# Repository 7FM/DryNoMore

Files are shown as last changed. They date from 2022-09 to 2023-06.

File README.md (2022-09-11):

# DryNoMore

TODO description, images, etc.

## Software

### Get the sources
- `git clone --recursive https://github.com/7FM/DryNoMore.git`
- Or `git clone https://github.com/7FM/DryNoMore.git` followed by `git submodule update --init --recursive`

### Dependencies
<details>
  <summary>For Debian:</summary>

```
apt install git git-lfs gcc make binutils cmake libssl-dev libboost-system-dev zlib1g-dev libyaml-cpp-dev 
```
Note that you will need `gcc-11` to compile the telegram bot, as it uses `std::bit_cast` (added in C++20).
Debian bullseye uses `gcc-10` by default and `g++-11` is currently only available in the testing channel.
Hence, you must add 
```
deb http://httpredir.debian.org/debian testing main contrib non-free
```
to `/etc/apt/sources.list`.
To avoid updating all packages to the testing channel create the file `/etc/apt/preferences.d/unstable-preferences` with the following content:
```
Package: *
Pin: release  a=testing
Pin-Priority: 100

Package: *
Pin: release a=unstable
Pin-Priority: 200
```
Then you can use `apt -t testing install gcc` to install `gcc-11`.
</details>

For NixOS see [`flake.nix`](./flake.nix).

### Compilation
- For the Arduino project simply use PlatformIO, i.e. through the [PlatformIO IDE](https://platformio.org/install/ide?install=vscode).
- For the Telegram Bot simply go into the folder `server/telegram_bot` and run `make`. On success a binary should be present at `server/telegram_bot/build/drynomore-telegram-bot`

### Configuration

<details>
  <summary>Configure the Arduino Project:</summary>

- all major settings are adjustable in the [`config.hpp`](./include/config.hpp)

TODO list options
</details>
<details>
  <summary>Configure the Telegram Bot:</summary>

- all major settings are adjustable though a YAML config file. As an example take a look at the [`example_config.yaml`](./server/telegram_bot/example_config.yaml).

TODO list options
</details>

## Hardware
### Known Flaws:
- v0.1:
    - Barrel Jack power input (J10) has swapped polarity.
- v0.2:
    - Main power consumption is caused by the W5500 Ethernet module

### Changelog:
#### v0.1 &rarr; v0.2:
- fix power input polarity
#### v0.2 &rarr; v0.3
- add mosfet to switch off the W5500 Ethernet module

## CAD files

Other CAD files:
hardware/case/DryNoMoreCase.FCStd
hardware/case/Top.stl
hardware/case/Base.stl

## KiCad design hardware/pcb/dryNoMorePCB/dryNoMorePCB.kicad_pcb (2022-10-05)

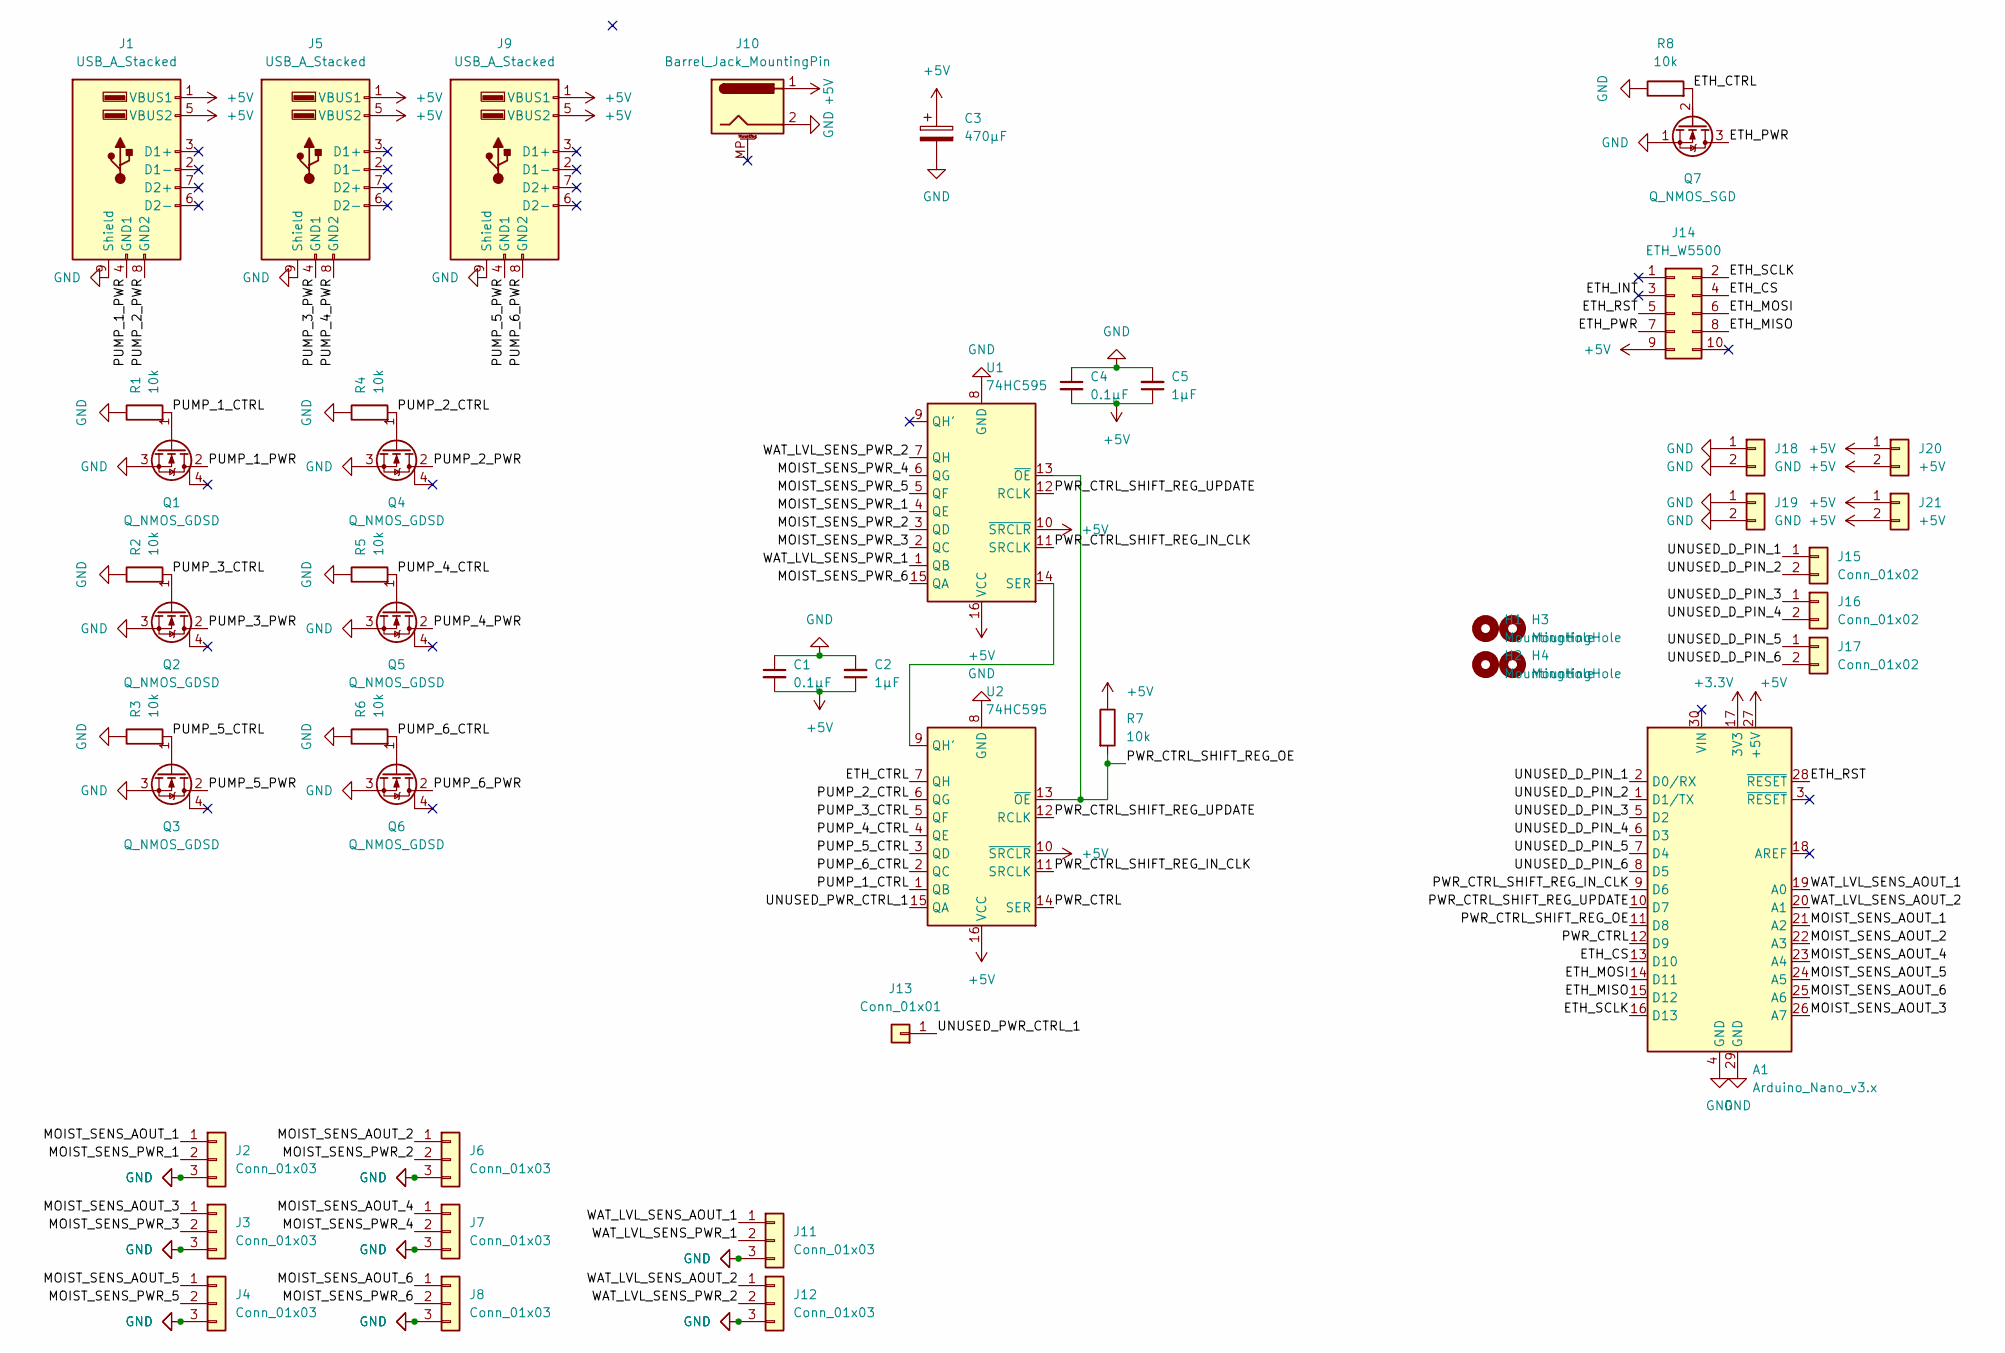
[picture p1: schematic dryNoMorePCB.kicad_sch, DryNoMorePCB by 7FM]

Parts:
A1: Arduino_Nano_v3.x; Arduino_Nano
C1, C4: 0.1µF; C_Disc_D3.8mm_W2.6mm_P2.50mm
C2, C5: 1µF; C_Rect_L4.0mm_W2.5mm_P2.50mm
C3: 470µF; CP_Radial_D8.0mm_P3.50mm
H1, H2, H3, H4: MountingHole; MountingHole_3.2mm_M3_DIN965
J1, J5, J9: USB_A_Stacked; USB_A_Wuerth_61400826021_Horizontal_Stacked
J2, J3, J4, J6, J7, J8, J11, J12: Conn_01x03; PinHeader_1x03_P2.54mm_Vertical
J10: Barrel_Jack_MountingPin; BarrelJack_Horizontal
J13: Conn_01x01; PinHeader_1x01_P2.54mm_Vertical
J14: ETH_W5500; PinSocket_2x05_P2.54mm_Vertical
J15, J16, J17: Conn_01x02; PinHeader_1x02_P2.54mm_Vertical
J18, J19: GND; PinHeader_1x02_P2.54mm_Vertical
J20, J21: +5V; PinHeader_1x02_P2.54mm_Vertical
Q1, Q2, Q3, Q4, Q5, Q6: Q_NMOS_GDSD; TO-220-3_Vertical
Q7: Q_NMOS_SGD; TO-92_Inline
R1, R2, R3, R4, R5, R6, R7: 10k; R_Axial_DIN0207_L6.3mm_D2.5mm_P7.62mm_Horizontal
R8: 10k; R_Axial_DIN0207_L6.3mm_D2.5mm_P2.54mm_Vertical
U1, U2: 74HC595; DIP-16_W7.62mm_Socket

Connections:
+3V3: A1.17 (3V3)
+5V: A1.27 (+5V), C1.2, C2.1, C3.1, C4.2, C5.1, J1.1 (VBUS1), J1.5 (VBUS2), J5.1 (VBUS1), J5.5 (VBUS2), J9.1 (VBUS1), J9.5 (VBUS2), J10.1, J14.9, J20.1, J20.2, J21.1, J21.2, R7.1, U1.10 (~SRCLR), U1.16 (VCC), U2.10 (~SRCLR), U2.16 (VCC); also elsewhere on the board
/ETH_CS: A1.13 (D10), J14.4
/ETH_CTRL: Q7.2 (G), R8.2, U2.7 (QH)
/ETH_INT: J14.3
/ETH_MISO: A1.15 (D12), J14.8
/ETH_MOSI: A1.14 (D11), J14.6
/ETH_PWR: J14.7, Q7.3 (D)
/ETH_RST: A1.28 (~RESET), J14.5
/ETH_SCLK: A1.16 (D13), J14.2
/MOIST_SENS_AOUT_1: A1.21 (A2), J2.1
/MOIST_SENS_AOUT_2: A1.22 (A3), J6.1
/MOIST_SENS_AOUT_3: A1.26 (A7), J3.1
/MOIST_SENS_AOUT_4: A1.23 (A4), J7.1
/MOIST_SENS_AOUT_5: A1.24 (A5), J4.1
/MOIST_SENS_AOUT_6: A1.25 (A6), J8.1
/MOIST_SENS_PWR_1: J2.2, U1.4 (QE)
/MOIST_SENS_PWR_2: J6.2, U1.3 (QD)
/MOIST_SENS_PWR_3: J3.2, U1.2 (QC)
/MOIST_SENS_PWR_4: J7.2, U1.6 (QG)
/MOIST_SENS_PWR_5: J4.2, U1.5 (QF)
/MOIST_SENS_PWR_6: J8.2, U1.15 (QA)
/PUMP_1_CTRL: Q1.1 (G), R1.2, U2.1 (QB)
/PUMP_1_PWR: J1.4 (GND1), Q1.2 (D); also elsewhere on the board
/PUMP_2_CTRL: Q4.1 (G), R4.2, U2.6 (QG)
/PUMP_2_PWR: J1.8 (GND2), Q4.2 (D); also elsewhere on the board
/PUMP_3_CTRL: Q2.1 (G), R2.2, U2.5 (QF)
/PUMP_3_PWR: J5.4 (GND1), Q2.2 (D); also elsewhere on the board
/PUMP_4_CTRL: Q5.1 (G), R5.2, U2.4 (QE)
/PUMP_4_PWR: J5.8 (GND2), Q5.2 (D); also elsewhere on the board
/PUMP_5_CTRL: Q3.1 (G), R3.2, U2.3 (QD)
/PUMP_5_PWR: J9.4 (GND1), Q3.2 (D); also elsewhere on the board
/PUMP_6_CTRL: Q6.1 (G), R6.2, U2.2 (QC)
/PUMP_6_PWR: J9.8 (GND2), Q6.2 (D); also elsewhere on the board
/PWR_CTRL: A1.12 (D9), U2.14 (SER)
/PWR_CTRL_SHIFT_REG_IN_CLK: A1.9 (D6), U1.11 (SRCLK), U2.11 (SRCLK)
/PWR_CTRL_SHIFT_REG_OE: A1.11 (D8), R7.2, U1.13 (~OE), U2.13 (~OE)
/PWR_CTRL_SHIFT_REG_UPDATE: A1.10 (D7), U1.12 (RCLK), U2.12 (RCLK)
/UNUSED_D_PIN_1: A1.2 (D0/RX), J15.1
/UNUSED_D_PIN_2: A1.1 (D1/TX), J15.2
/UNUSED_D_PIN_3: A1.5 (D2), J16.1
/UNUSED_D_PIN_4: A1.6 (D3), J16.2
/UNUSED_D_PIN_5: A1.7 (D4), J17.1
/UNUSED_D_PIN_6: A1.8 (D5), J17.2
/UNUSED_PWR_CTRL_1: J13.1, U2.15 (QA)
/WAT_LVL_SENS_AOUT_1: A1.19 (A0), J11.1
/WAT_LVL_SENS_AOUT_2: A1.20 (A1), J12.1
/WAT_LVL_SENS_PWR_1: J11.2, U1.1 (QB)
/WAT_LVL_SENS_PWR_2: J12.2, U1.7 (QH)
GND: A1.4 (GND), A1.29 (GND), C1.1, C2.2, C3.2, C4.1, C5.2, J1.9 (Shield), J2.3, J3.3, J4.3, J5.9 (Shield), J6.3, J7.3, J8.3, J9.9 (Shield), J10.2, J11.3, J12.3, J18.1, J18.2, J19.1, J19.2, Q1.3 (S), Q2.3 (S), Q3.3 (S), Q4.3 (S), Q5.3 (S), Q6.3 (S), Q7.1 (S), R1.1, R2.1, R3.1, R4.1, R5.1, R6.1, R8.1, U1.8 (GND), U2.8 (GND); also elsewhere on the board
unnamed: U1.14 (SER), U2.9 (QH')

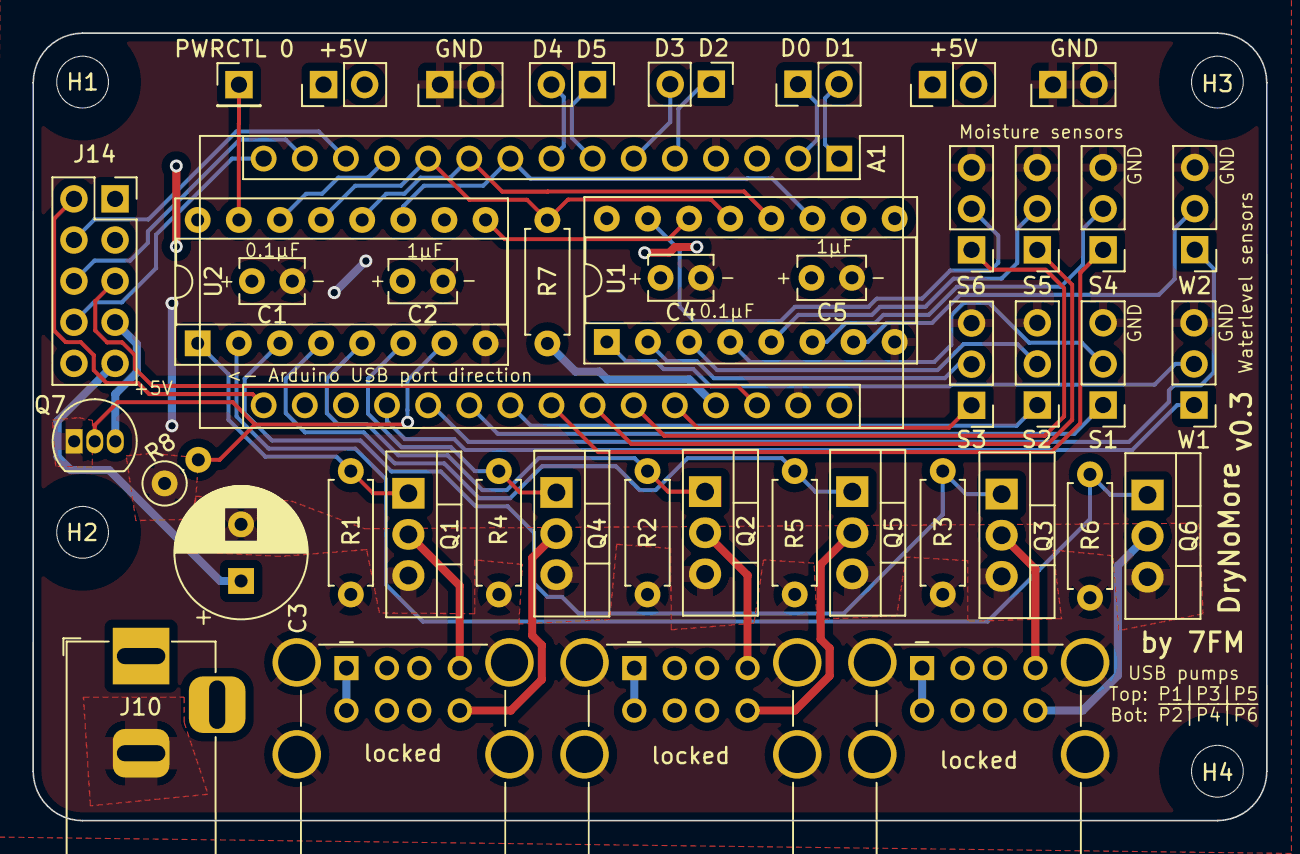
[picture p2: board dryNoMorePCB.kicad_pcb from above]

Board: 2 copper layers, 76.2 x 48.6 mm, 48 parts (0 on the bottom side), 49 nets.

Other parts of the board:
locked: USB_A_Stacked; USB_A_Wuerth_61400826021_Horizontal_Stacked
locked#2, locked#3: USB_A_Stacked; USB_A_Wuerth_61400826021_Horizontal_Stacked

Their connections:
+5V: locked.1 (VBUS1), locked.5 (VBUS2), locked#2.1 (VBUS1), locked#2.5 (VBUS2), locked#3.1 (VBUS1), locked#3.5 (VBUS2); also elsewhere on the board
/PUMP_1_PWR: locked.4 (GND1); also elsewhere on the board
/PUMP_2_PWR: locked.8 (GND2); also elsewhere on the board
/PUMP_3_PWR: locked#3.4 (GND1); also elsewhere on the board
/PUMP_4_PWR: locked#3.8 (GND2); also elsewhere on the board
/PUMP_5_PWR: locked#2.4 (GND1); also elsewhere on the board
/PUMP_6_PWR: locked#2.8 (GND2); also elsewhere on the board
GND: locked.9 (Shield), locked#2.9 (Shield), locked#3.9 (Shield); also elsewhere on the board

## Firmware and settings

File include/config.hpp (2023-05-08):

#pragma once

// #define BOARD_VERSION 0x0010 /*v0.1*/
// #define BOARD_VERSION 0x0020 /*v0.2*/
#define BOARD_VERSION 0x0030 /*v0.3*/

// Configure modes
// #define DUMP_SOIL_MOISTURES_MEASUREMENTS
#ifndef DUMP_SOIL_MOISTURES_MEASUREMENTS
// #define DUMP_WATER_LEVEL_MEASUREMENTS
#endif

// Enable debug serial prints
// #define DEBUG_SERIAL_PRINTS
// #define DEBUG_NORMAL_CPU_SPEED

#if !defined(DUMP_SOIL_MOISTURES_MEASUREMENTS) &&                              \
    !defined(DUMP_WATER_LEVEL_MEASUREMENTS)
// No serial needed
#define DISABLE_SERIAL
#else
#warning "Running in setup mode, this won't irrigate your flowers!"
#warning "Disable both DUMP_SOIL_MOISTURES_MEASUREMENTS and "                       \
    "DUMP_WATER_LEVEL_MEASUREMENTS in include/config.hpp to run in production mode"
#endif

#define USE_ETHERNET
#ifdef USE_ETHERNET

#define MAC_ADDRESS                                                            \
  { 0xDE, 0xAD, 0xBE, 0xEF, 0xFE, 0xED }

#define LOCAL_NETWORK_SUBNET 192, 168, 0
#define FALLBACK_IP LOCAL_NETWORK_SUBNET, 254
#define FALLBACK_DNS LOCAL_NETWORK_SUBNET, 1
#define LOCAL_SERVER_IP LOCAL_NETWORK_SUBNET, 42
#define LOCAL_SERVER_PORT 42424
#else
// SPI will be required for the Ethernet connection
#define DISABLE_SPI
#endif

// Config

// We can't increase the serial speed much with our low CPU frequency!
#ifdef DEBUG_NORMAL_CPU_SPEED
#define SERIAL_BAUD_RATE 9600
#else
#define SERIAL_BAUD_RATE 600
#endif

#define MEASURE_DELAY_MS 200
#define POWER_ON_DELAY_MS 500
#define ADC_MEASUREMENTS 5

// time between moisture checks: default every 6 hours
#define SLEEP_PERIOD_MIN static_cast<uint16_t>(6) * 60

#define SHIFT_REG_DATA_CLK_PIN 6
#define SHIFT_REG_OUTPUT_UPDATE_PIN 7
#define SHIFT_REG_OUTPUT_EN_PIN 8
#define SHIFT_REG_DATA_PIN 9

#define MOISTURE_SENSOR_PINS                                                   \
  { A2, A3, A7, A4, A5, A6 }

#define WATER_SENSOR_PINS                                                      \
  { A0, A1 }

#ifdef DEBUG_SERIAL_PRINTS
// Reactivate the serial port if we desire serial prints!
#ifdef DISABLE_SERIAL
#undef DISABLE_SERIAL
#endif
#endif

#ifdef DISABLE_SERIAL
#define FREE_DIGITAL_PINS                                                      \
  { /*D*/ 0, /*D*/ 1, /*D*/ 2, /*D*/ 3, /*D*/ 4, /*D*/ 5 }
#else
#define FREE_DIGITAL_PINS                                                      \
  { /*D*/ 2, /*D*/ 3, /*D*/ 4, /*D*/ 5 }
#endif

// uint16_t shiftReg: P = Pump, M = moisture sensor, W = water sensor
// { UNUSED_1, P1, P6, P5, P4, P3, P2, UNUSED_2, M6, W1, M3, M2, M1, M5, M4, W2
// }
//   ^--- MSb                                                         LSb ---^
#define PUMP_PWR_MAPPING                                                       \
  {                                                                            \
    (static_cast<uint16_t>(1) << 14),     /* Pump 1 */                         \
        (static_cast<uint16_t>(1) << 9),  /* Pump 2 */                         \
        (static_cast<uint16_t>(1) << 10), /* Pump 3 */                         \
        (static_cast<uint16_t>(1) << 11), /* Pump 4 */                         \
        (static_cast<uint16_t>(1) << 12), /* Pump 5 */                         \
        (static_cast<uint16_t>(1) << 13)  /* Pump 6 */                         \
  }

#define MOIST_SENS_PWR_MAPPING                                                 \
  {                                                                            \
    (static_cast<uint16_t>(1) << 3),     /* Sens 1 */                          \
        (static_cast<uint16_t>(1) << 4), /* Sens 2 */                          \
        (static_cast<uint16_t>(1) << 5), /* Sens 3 */                          \
        (static_cast<uint16_t>(1) << 1), /* Sens 4 */                          \
        (static_cast<uint16_t>(1) << 2), /* Sens 5 */                          \
        (static_cast<uint16_t>(1) << 7)  /* Sens 6 */                          \
  }

#define WATER_SENS_PWR_MAPPING                                                 \
  {                                                                            \
    (static_cast<uint16_t>(1) << 6),    /* Sens 1 */                           \
        (static_cast<uint16_t>(1) << 0) /* Sens 2 */                           \
  }

#if BOARD_VERSION >= 0x0030
#define ETH_PWR_MAPPING (static_cast<uint16_t>(1) << 8) /* Unused 2 */
#define UNUSED_PWR_MAPPING                                                     \
  { (static_cast<uint16_t>(1) << 15) /* Unused 1 */ }

#else
#define UNUSED_PWR_MAPPING                                                     \
  {                                                                            \
    (static_cast<uint16_t>(1) << 15),   /* Unused 1 */                         \
        (static_cast<uint16_t>(1) << 8) /* Unused 2 */                         \
  }
#endif

#define DEFAULT_NUM_PLANTS 1

#define DEFAULT_MOISTURE_MIN_VALUES                                            \
  { 200, 200, 200, 200, 200, 200 }
#define DEFAULT_MOISTURE_MAX_VALUES                                            \
  { 500, 500, 500, 500, 500, 500 }
#define DEFAULT_MOISTURE_TARGET_THRESHOLDS                                     \
  { 50, 50, 50, 50, 50, 50 }
#define DEFAULT_MOIST_TO_WATER_MAPPINGS                                        \
  { 0, 0, 0, 0, 0, 0 }
#define DEFAULT_PLANT_SKIP_VALUES                                              \
  { 1, 1, 1, 1, 1, 1 }
#define DEFAULT_BURST_DURATION_SEC                                             \
  { 2, 2, 2, 2, 2, 2 }
#define DEFAULT_BURST_DELAY_SEC                                                \
  { 5, 5, 5, 5, 5, 5 }
#define DEFAULT_MAX_BURSTS                                                     \
  { 5, 5, 5, 5, 5, 5 }

#define DEFAULT_WATER_MIN_VALUES                                               \
  { 180, 180 }
#define DEFAULT_WATER_MAX_VALUES                                               \
  { 480, 480 }
#define DEFAULT_WATER_WARNING_THRESHOLDS                                       \
  { 50, 50 }
#define DEFAULT_WATER_EMPTY_THRESHOLDS                                         \
  { 20, 20 }

#ifndef DISABLE_SERIAL
#warning                                                                       \
    "Disabling serial is strongly recommended in production mode to avoid "    \
    "unnecessary runtime as well as power consumption!"
#endif

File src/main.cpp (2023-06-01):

#include "config.hpp"

#include "adc_measurement.hpp"
#include "lan.hpp"
#include "macros.hpp"
#include "power_ctrl.hpp"
#include "serial.hpp"
#include "settings.hpp"
#include "sleep.hpp"

#include <Arduino.h>

// Consts
static constexpr decltype(A0) moistSensPins[] = MOISTURE_SENSOR_PINS;
static constexpr decltype(A0) waterSensPins[] = WATER_SENSOR_PINS;
static constexpr decltype(A0) unusedDigitalPins[] = FREE_DIGITAL_PINS;

static constexpr uint16_t moistSensPwrMap[] = MOIST_SENS_PWR_MAPPING;
static constexpr uint16_t waterSensPwrMap[] = WATER_SENS_PWR_MAPPING;
static constexpr uint16_t pumpPwrMap[] = PUMP_PWR_MAPPING;

// Global vars
static const ShiftReg shiftReg;
static Settings settings;
static Status status;

static inline bool isSoilTooDry(uint8_t pin, uint16_t min, uint16_t max,
                                uint8_t target, uint8_t &measurement,
                                uint16_t &rawMeasurement) {
  SERIALprintP(PSTR("Measured soil moisture"));
  measurement = clampedMeasurement(pin, min, max, rawMeasurement);
  return measurement < target;
}

static inline bool waterTankNotEmpty(uint8_t pin, uint16_t min, uint16_t max,
                                     uint8_t empty, uint8_t &measurement,
                                     uint16_t &rawMeasurement) {
  SERIALprintP(PSTR("Measured water tank level"));
  measurement = clampedMeasurement(pin, min, max, rawMeasurement);
  bool isEmpty = measurement <= empty;
  return !isEmpty;
}

static uint8_t checkMoisture(uint8_t idx, Status &status,
                             uint16_t &secondsPassed) {
  const auto pumpMask = pumpPwrMap[idx];
  const auto moistPin = moistSensPins[idx];
  const auto moistSensMask = moistSensPwrMap[idx];

  const auto moistMin = settings.sensConfs[idx].minValue;
  const auto moistMax = settings.sensConfs[idx].maxValue;
  const auto moistTarget = settings.targetMoisture[idx];
  const auto burstDelay = settings.burstDelay[idx];
  const auto maxBursts = settings.maxBursts[idx];

  const uint8_t waterSensIdx = (settings.moistSensToWaterSensBitmap[idx / 8] >>
                                (idx & 7 /*aka mod 8*/)) &
                               0x01;

  const auto waterPin = waterSensPins[waterSensIdx];
  const auto waterSensMask = waterSensPwrMap[waterSensIdx];

  const uint8_t offsetIdx = (MAX_MOISTURE_SENSOR_COUNT) + waterSensIdx;
  const auto waterMin = settings.sensConfs[offsetIdx].minValue;
  const auto waterMax = settings.sensConfs[offsetIdx].maxValue;
  const auto waterWarning = settings.waterLvlThres[waterSensIdx].warnThres;
  const auto waterEmpty = settings.waterLvlThres[waterSensIdx].emptyThres;

  shiftReg.update(moistSensMask | waterSensMask);
  _delay_ms(POWER_ON_DELAY_MS);

  // timeout to ensure we are not stuck here forever (and flood the plants) in
  // case of an defect sensor/pump
  constexpr uint32_t measurementDuration =
      (static_cast<uint32_t>(ADC_MEASUREMENTS) * (MEASURE_DELAY_MS));
  const uint8_t burstCycles =
      (static_cast<uint32_t>(settings.burstDuration[idx]) * 1000 +
       measurementDuration - 1) /
      measurementDuration;

  uint16_t rawWaterMeasurement = UNDEFINED_LEVEL_16;
  uint16_t rawMoistMeasurement = UNDEFINED_LEVEL_16;
  uint8_t waterMeasurement = UNDEFINED_LEVEL_8;
  uint8_t moistMeasurement = UNDEFINED_LEVEL_8;

  auto initCheck = [&]() {
    if (status.beforeWaterLevels[waterSensIdx] == UNDEFINED_LEVEL_8) {
      status.beforeWaterLevels[waterSensIdx] = waterMeasurement;
    }
    if (status.beforeMoistureLevels[idx] == UNDEFINED_LEVEL_8) {
      status.beforeMoistureLevels[idx] = moistMeasurement;
    }
    if (status.beforeWaterLevelsRaw[waterSensIdx] == UNDEFINED_LEVEL_16) {
      status.beforeWaterLevelsRaw[waterSensIdx] = rawWaterMeasurement;
    }
    if (status.beforeMoistureLevelsRaw[idx] == UNDEFINED_LEVEL_16) {
      status.beforeMoistureLevelsRaw[idx] = rawMoistMeasurement;
    }
  };

  bool soilIsTooDry = false;
  bool hasWaterLeft = false;
  uint8_t burst = 0;
  uint8_t burstCycle = 0;
  for (; burst < maxBursts; ++burst) {
    // Check soil moisture once, if it is too low, then irrigate a whole burst!
    // After the wait time, check again. This avoids stopping the irrigation
    // because the sensor is covered with water and the water does not
    // immediately seep into the earth.
    if (!(soilIsTooDry = isSoilTooDry(moistPin, moistMin, moistMax, moistTarget,
                                      moistMeasurement, rawMoistMeasurement))) {
      goto stop_irrigation;
    }

    for (; burstCycle < burstCycles; ++burstCycle) {
      if (!(hasWaterLeft =
                waterTankNotEmpty(waterPin, waterMin, waterMax, waterEmpty,
                                  waterMeasurement, rawWaterMeasurement))) {
        goto stop_irrigation;
      }

      if (burstCycle == 0) {
        shiftReg.update(moistSensMask | waterSensMask | pumpMask);
        if (burst == 0) {
          initCheck();
        }
      }
    }
    burstCycle = 0;

    if (burstDelay > 0) {
      // Turn off the pump and wait approx. X seconds
      shiftReg.update(moistSensMask | waterSensMask);
      secondsPassed += burstDelay;
      sleepSec(burstDelay);
    }
  }

stop_irrigation:
  // Finally turn the power of the sensors and the pump off
  shiftReg.disableOutput();
  shiftReg.update(0);
  shiftReg.enableOutput();

  // also add the measurement delays to the seconds passed!
  secondsPassed += static_cast<uint16_t>(
      (static_cast<uint32_t>(
           burst * (burstCycles +
                    1 /*measuring the soil only once before every burst*/) +
           burstCycle) *
       measurementDuration) /
      1000);
  // Less precise but faster measurement delay calculation
  // secondsPassed += static_cast<uint16_t>(burst * burstCycles + burstCycle) *
  //                  settings.burstDuration[idx];

  settings.hardwareFailure = soilIsTooDry && hasWaterLeft;
  initCheck();
  status.afterWaterLevelsRaw[waterSensIdx] = rawWaterMeasurement;
  status.afterWaterLevels[waterSensIdx] = waterMeasurement;
  status.afterMoistureLevelsRaw[idx] = rawMoistMeasurement;
  status.afterMoistureLevels[idx] = moistMeasurement;

  uint8_t retCode =
      (hasWaterLeft ? 0 : 0x02) | (waterMeasurement <= waterWarning ? 0x01 : 0);
  return retCode << (waterSensIdx << 1);
}

static void disableDigitalOnAnalogPins() {
  // disable digital input buffer on analog pins, as not used and saves energy
  DIDR0 = _BV(ADC0D) | _BV(ADC1D) | _BV(ADC2D) | _BV(ADC3D) | _BV(ADC4D) |
          _BV(ADC5D);
  DIDR1 = _BV(AIN0D) | _BV(AIN1D);
}

static void powerSavingSettings() {
  // reduce the clock speed for a lower power consumption
#ifndef DEBUG_NORMAL_CPU_SPEED
  noInterrupts();
  // To avoid unintentional changes of clock frequency, a special write
  // procedure must be followed to change the CLKPS bits:
  // 1. Write the clock prescaler change enable (CLKPCE) bit to one and all
  // other bits in CLKPR to zero.
  CLKPR = _BV(CLKPCE);
  // 2. Within four cycles, write the desired value to CLKPS while writing a
  // zero to CLKPCE. division factor of 256!!! We are getting really really
  // slow... 16 MHz / 256 = 62.5 kHz
  CLKPR = _BV(CLKPS3);
  interrupts();
#endif

  // Turn off all unused modules:
  // NOTE that you can not use delay(), millis(), etc. afterwards!
  // Disable all timer interrupts:
  TIMSK0 = 0; /*Disable Timer0 interrupts*/
  TIMSK1 = 0; /*Disable Timer1 interrupts*/
  TIMSK2 = 0; /*Disable Timer2 interrupts*/
  // Power down modules:
  PRR = _BV(PRTWI) /*Shutdown TWI*/ | _BV(PRTIM2) /*Shutdown Timer2*/ |
        _BV(PRTIM1) /*Shutdown Timer1*/ | _BV(PRTIM0) /*Shutdown Timer0*/
#ifdef DISABLE_SPI
        | _BV(PRSPI) /*Shutdown SPI*/
#endif
#ifdef DISABLE_SERIAL
        | _BV(PRUSART0) /*Shutdown USART, needed for Hardware Serial*/
#endif
      ;

  disableDigitalOnAnalogPins();
}

static void setStatusUndef(Status &status) {
  for (uint8_t i = 0; i < (MAX_MOISTURE_SENSOR_COUNT); ++i) {
    status.beforeMoistureLevels[i] = UNDEFINED_LEVEL_8;
    status.afterMoistureLevels[i] = UNDEFINED_LEVEL_8;
    status.beforeMoistureLevelsRaw[i] = UNDEFINED_LEVEL_16;
    status.afterMoistureLevelsRaw[i] = UNDEFINED_LEVEL_16;
  }
  for (uint8_t i = 0; i < 2; ++i) {
    status.beforeWaterLevels[i] = UNDEFINED_LEVEL_8;
    status.afterWaterLevels[i] = UNDEFINED_LEVEL_8;
    status.beforeWaterLevelsRaw[i] = UNDEFINED_LEVEL_16;
    status.afterWaterLevelsRaw[i] = UNDEFINED_LEVEL_16;
  }
}

static void defaultInitStatus(Status &status) {
  for (auto &t : status.ticksSinceIrrigation) {
    t = 255;
  }
}

static void analogPowerSave() {
  // TODO we might prefer output LOW for connected sensors as they have an
  // capacitor and resistor connected to this pin
  for (auto p : moistSensPins) {
    // pinMode(p, INPUT_PULLUP);
    pinMode(p, OUTPUT);
    digitalWrite(p, LOW);
  }
  for (auto p : waterSensPins) {
    // pinMode(p, INPUT_PULLUP);
    pinMode(p, OUTPUT);
    digitalWrite(p, LOW);
  }
}

static void deinitUnusedAnalogPins() {
  for (uint8_t i = settings.numPlants; i < CONST_ARRAY_SIZE(moistSensPins);
       ++i) {
    // pinMode(moistSensPins[i], INPUT_PULLUP);
    pinMode(moistSensPins[i], OUTPUT);
    digitalWrite(moistSensPins[i], LOW);
  }
  const uint8_t usedWaterSens = getUsedWaterSens(settings);
  for (uint8_t i = usedWaterSens; i < CONST_ARRAY_SIZE(waterSensPins); ++i) {
    // pinMode(waterSensPins[i], INPUT_PULLUP);
    pinMode(waterSensPins[i], OUTPUT);
    digitalWrite(waterSensPins[i], LOW);
  }
}

static void initAnalogPins() {
  for (uint8_t i = 0; i < CONST_ARRAY_SIZE(moistSensPins); ++i) {
    pinMode(moistSensPins[i], INPUT);
  }
  for (uint8_t i = 0; i < CONST_ARRAY_SIZE(waterSensPins); ++i) {
    pinMode(waterSensPins[i], INPUT);
  }
}

void setup() {
  // Sanity checks
  static_assert(CONST_ARRAY_SIZE(moistSensPins) ==
                CONST_ARRAY_SIZE(moistSensPwrMap));
  static_assert(CONST_ARRAY_SIZE(moistSensPins) == (MAX_MOISTURE_SENSOR_COUNT));
  static_assert(CONST_ARRAY_SIZE(waterSensPins) ==
                CONST_ARRAY_SIZE(waterSensPwrMap));
  static_assert(CONST_ARRAY_SIZE(waterSensPins) == 2);
  static_assert((MAX_MOISTURE_SENSOR_COUNT) == CONST_ARRAY_SIZE(pumpPwrMap));

  powerSavingSettings();
  analogPowerSave();

  // Heavily discussed in
  // https://arduino.stackexchange.com/questions/88319/power-saving-configuration-of-unconnected-pins
  // TLDR; either INPUT_PULLUP or OUTPUT LOW where INPUT_PULLUP seems to suffer
  // a bit from leakage current
  // However if we set the TX & RX pins to LOW then their LEDs will always be
  // on! so lets settle with INPUT_PULLUP and hope that the leakage current is
  // much lower than powering the LEDs!
  for (auto p : unusedDigitalPins) {
    if (p == /*D*/ 0 || p == /*D*/ 1) {
      pinMode(p, INPUT_PULLUP);
    } else {
      pinMode(p, OUTPUT);
      digitalWrite(p, LOW);
    }
  }

  SERIALbegin(SERIAL_BAUD_RATE);
  SERIALprintlnP(PSTR("Setup Ethernet"));
  setupEthernet(shiftReg);
  SERIALprintlnP(PSTR("Done: Setup Ethernet"));

  defaultInitSettings(settings);
  defaultInitStatus(status);
}

void loop() {

  // ===================================================================
  // Setup modes
  // ===================================================================
#ifdef DUMP_SOIL_MOISTURES_MEASUREMENTS
  initAnalogPins();
  deinitUnusedAnalogPins();
  for (uint8_t idx = 0; idx < settings.numPlants; ++idx) {
    const auto moistPin = moistSensPins[idx];
    const auto moistSensMask = moistSensPwrMap[idx];

    const auto moistMin = settings.sensConfs[idx].minValue;
    const auto moistMax = settings.sensConfs[idx].maxValue;
    const auto moistTarget = settings.targetMoisture[idx];

    shiftReg.update(moistSensMask);
    shiftReg.enableOutput();
    _delay_ms(POWER_ON_DELAY_MS);

    uint8_t measurement;
    uint16_t rawMeasurement;
    isSoilTooDry(moistPin, moistMin, moistMax, moistTarget, measurement,
                 rawMeasurement);

    // Finally turn the power of the sensors and the pump off
    shiftReg.disableOutput();
  }
#elif defined(DUMP_WATER_LEVEL_MEASUREMENTS)
  initAnalogPins();
  deinitUnusedAnalogPins();
  const uint8_t usedWaterSens = getUsedWaterSens(settings);
  for (uint8_t idx = 0; idx < usedWaterSens; ++idx) {
    const auto waterPin = waterSensPins[idx];
    const auto waterSensMask = waterSensPwrMap[idx];

    const uint8_t offsetIdx = (MAX_MOISTURE_SENSOR_COUNT) + idx;
    const auto waterMin = settings.sensConfs[offsetIdx].minValue;
    const auto waterMax = settings.sensConfs[offsetIdx].maxValue;
    // const auto waterWarning = settings.waterLvlThres[idx].warnThres;
    const auto waterEmpty = settings.waterLvlThres[idx].emptyThres;

    shiftReg.update(waterSensMask);
    shiftReg.enableOutput();
    _delay_ms(POWER_ON_DELAY_MS);

    uint8_t measurement;
    uint16_t rawMeasurement;
    waterTankNotEmpty(waterPin, waterMin, waterMax, waterEmpty, measurement,
                      rawMeasurement);

    // Finally turn the power of the sensors and the pump off
    shiftReg.disableOutput();
  }
#else
  // ===================================================================
  // Production mode
  // ===================================================================

  SERIALprintlnP(PSTR("Running irrigation routine!"));

  // Switch to normal input mode early to ensure enough time to discharge all
  // caps
  initAnalogPins();
  // allow remote to reset the hardware failure flag
  if (powerUpEthernet(shiftReg)) {
    updateSettings(settings);
  }
  deinitUnusedAnalogPins();
  powerDownEthernet(shiftReg);

  uint16_t secondsPassed = 0;
  if (!settings.hardwareFailure) {
    bool statusChanged = false;
    setStatusUndef(status);
    status.numPlants = settings.numPlants;
    status.numWaterSensors = getUsedWaterSens(settings);

    // 2 bits per water level sensor: 1 to request a warning, 1 to send an error
    // that the water is empty! the lsb bits are used for the first sensor.
    uint8_t resCode = 0;

    shiftReg.update(0);
    shiftReg.enableOutput();

    SERIALprintlnP(PSTR("Irrigation running!"));
    uint8_t idx = 0;
    for (; !settings.hardwareFailure && idx < settings.numPlants; ++idx) {
      bool skip = status.ticksSinceIrrigation[idx] <
                      settings.ticksBetweenIrrigation[idx] ||
                  ((settings.skipBitmap[idx / 8] >> (idx & 7 /*aka mod 8*/)) &
                   0x01) != 0;
      statusChanged |= !skip;
      if (!skip) {
        // This ensures that the tick counter will overflow to 0 -> reset its
        // value!
        status.ticksSinceIrrigation[idx] = 255;
        resCode |= checkMoisture(idx, status, secondsPassed);
      }
    }

    shiftReg.disableOutput();
    shiftReg.update(0);
    analogPowerSave();

    // Update the tick counters!
    for (auto &t : status.ticksSinceIrrigation) {
      ++t;
    }

    // Only send messages if the status changed!
    statusChanged |= settings.debug;
    SERIALprintP(PSTR("Status changed: "));
    SERIALprintln(statusChanged);
    if (statusChanged || settings.hardwareFailure) {
      SERIALprintlnP(PSTR("Send status updates!"));
      if (powerUpEthernet(shiftReg)) {
        if (statusChanged) {
          sendStatus(status);
          for (uint8_t i = 0; resCode != 0 && i < 2; ++i, resCode >>= 2) {
            if (resCode & 0x02) {
              sendErrorWaterEmpty(i);
            } else if (resCode & 0x01) {
              sendWarning(i);
            }
          }
        }
        if (settings.hardwareFailure) {
          // Send HW error message!
          sendErrorHardware(idx - 1);
        }
      }
      powerDownEthernet(shiftReg);
    }
  } else {
    analogPowerSave();
    // Update the tick counters!
    for (auto &t : status.ticksSinceIrrigation) {
      // prevent overflows!
      t = max(t, t + 1);
    }
  }
  SERIALprintlnP(PSTR("Entering long sleep!"));
  sleepSec(SLEEP_PERIOD_MIN * 60 - secondsPassed);
#endif
}

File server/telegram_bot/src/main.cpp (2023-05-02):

#include <fstream>
#include <iostream>
#include <signal.h>
#include <thread>
#include <type_traits>
#include <yaml-cpp/yaml.h>

#include "dry_no_more_server.hpp"
#include "networking.hpp"
#include "telegram_bot.hpp"

static std::atomic<bool> running(true);

static void signalHandler(int signal) {
  if (signal == SIGINT || signal == SIGTERM) {
    running.store(false);
  }
}

// This code is required to change uint8_t values to uint16_t otherwise YAML
// export and import treats the values as characters!
template <class T>
struct ____yaml_dec_type {
  typedef T type;
};
template <>
struct ____yaml_dec_type<uint8_t> {
  typedef uint16_t type;
};
template <class T>
struct yaml_dec_type {
  typedef ____yaml_dec_type<std::remove_cvref_t<T>>::type type;
};
template <class T>
using yaml_dec_type_t = typename yaml_dec_type<T>::type;
template <class T>
yaml_dec_type_t<T> yaml_encode(T t) {
  return static_cast<yaml_dec_type_t<T>>(t);
}

namespace YAML {
  template <>
  struct convert<SensConfig> {
    static Node encode(const SensConfig &conf) {
      Node node;
      node["minValue"] = yaml_encode(conf.minValue);
      node["maxValue"] = yaml_encode(conf.maxValue);
      return node;
    }

    static bool decode(const Node &node, SensConfig &conf) {
      conf.minValue =
          node["minValue"].as<yaml_dec_type_t<decltype(conf.minValue)>>();
      conf.maxValue =
          node["maxValue"].as<yaml_dec_type_t<decltype(conf.maxValue)>>();
      return true;
    }
  };
} // namespace YAML

namespace YAML {
  template <>
  struct convert<WaterLvlThresholds> {
    static Node encode(const WaterLvlThresholds &conf) {
      Node node;
      node["warnThres"] = yaml_encode(conf.warnThres);
      node["emptyThres"] = yaml_encode(conf.emptyThres);
      return node;
    }

    static bool decode(const Node &node, WaterLvlThresholds &conf) {
      conf.warnThres =
          node["warnThres"].as<yaml_dec_type_t<decltype(conf.warnThres)>>();
      conf.emptyThres =
          node["emptyThres"].as<yaml_dec_type_t<decltype(conf.emptyThres)>>();
      return true;
    }
  };
} // namespace YAML

namespace YAML {
  template <>
  struct convert<Settings> {
    static Node encode(const Settings &set) {
      Node node;

      auto sensConfNode = node["sensConf"];
      auto waterThresNode = node["waterLvlThres"];
      auto targetMoistNode = node["targetMoisture"];
      auto burstDurationNode = node["burstDuration"];
      auto burstDelayNode = node["burstDelay"];
      auto maxBurstsNode = node["maxBursts"];
      auto ticksBetweenIrrigationNode = node["ticksBetweenIrrigation"];
      auto moistSensToWaterSensBitmapNode = node["moistSensToWaterSensBitmap"];
      auto skipBitmapNode = node["skipBitmap"];

      for (const auto &w : set.waterLvlThres) {
        waterThresNode.push_back(w);
      }
      for (const auto &s : set.sensConfs) {
        sensConfNode.push_back(s);
      }
      for (unsigned i = 0; i < MAX_MOISTURE_SENSOR_COUNT; ++i) {
        targetMoistNode.push_back(yaml_encode(set.targetMoisture[i]));
        burstDurationNode.push_back(yaml_encode(set.burstDuration[i]));
        burstDelayNode.push_back(yaml_encode(set.burstDelay[i]));
        maxBurstsNode.push_back(yaml_encode(set.maxBursts[i]));
        ticksBetweenIrrigationNode.push_back(
            yaml_encode(set.ticksBetweenIrrigation[i]));

        // handle bitmaps
        bool val = (set.moistSensToWaterSensBitmap[i / 8] &
                    (static_cast<uint8_t>(1) << (i & 7 /*aka mod 8*/))) != 0;
        moistSensToWaterSensBitmapNode.push_back(yaml_encode(val));
        val = (set.skipBitmap[i / 8] &
               (static_cast<uint8_t>(1) << (i & 7 /*aka mod 8*/))) != 0;
        skipBitmapNode.push_back(yaml_encode(val));
      }
      node["numPlants"] = yaml_encode(set.numPlants);
      node["hardwareFailure"] = yaml_encode(set.hardwareFailure);
      node["debug"] = yaml_encode(set.debug);

      return node;
    }

    static bool decode(const Node &node, Settings &set) {
      // clear bitmaps
      for (auto &s : set.moistSensToWaterSensBitmap) {
        s = 0;
      }
      for (auto &s : set.skipBitmap) {
        s = 0;
      }

      const auto &sensConfNode = node["sensConf"];
      const auto &waterThresNode = node["waterLvlThres"];
      const auto &targetMoistNode = node["targetMoisture"];
      const auto &burstDurationNode = node["burstDuration"];
      const auto &burstDelayNode = node["burstDelay"];
      const auto &maxBurstsNode = node["maxBursts"];
      const auto &ticksBetweenIrrigationNode = node["ticksBetweenIrrigation"];
      const auto &moistSensToWaterSensBitmapNode =
          node["moistSensToWaterSensBitmap"];
      const auto &skipBitmapNode = node["skipBitmap"];

      unsigned i = 0;
      for (auto &w : set.waterLvlThres) {
        w = waterThresNode[i].as<yaml_dec_type_t<decltype(w)>>();
        ++i;
      }
      i = 0;
      for (auto &s : set.sensConfs) {
        s = sensConfNode[i].as<yaml_dec_type_t<decltype(s)>>();
        ++i;
      }
      for (i = 0; i < MAX_MOISTURE_SENSOR_COUNT; ++i) {
        set.targetMoisture[i] =
            targetMoistNode[i]
                .as<yaml_dec_type_t<decltype(set.targetMoisture[i])>>();
        set.burstDuration[i] =
            burstDurationNode[i]
                .as<yaml_dec_type_t<decltype(set.burstDuration[i])>>();
        set.burstDelay[i] =
            burstDelayNode[i]
                .as<yaml_dec_type_t<decltype(set.burstDelay[i])>>();
        set.maxBursts[i] =
            maxBurstsNode[i].as<yaml_dec_type_t<decltype(set.maxBursts[i])>>();
        set.ticksBetweenIrrigation[i] =
            ticksBetweenIrrigationNode[i]
                .as<yaml_dec_type_t<decltype(set.ticksBetweenIrrigation[i])>>();

        // handle bitmaps
        bool val = moistSensToWaterSensBitmapNode[i]
                       .as<yaml_dec_type_t<decltype(val)>>();
        set.moistSensToWaterSensBitmap[i / 8] |=
            val ? (1 << (i & 7 /*aka mod 8*/)) : 0;
        val = skipBitmapNode[i].as<yaml_dec_type_t<decltype(val)>>();
        set.skipBitmap[i / 8] |= val ? (1 << (i & 7 /*aka mod 8*/)) : 0;
      }
      set.numPlants =
          node["numPlants"].as<yaml_dec_type_t<decltype(set.numPlants)>>();
      set.hardwareFailure =
          node["hardwareFailure"]
              .as<yaml_dec_type_t<decltype(set.hardwareFailure)>>();
      set.debug = node["debug"].as<yaml_dec_type_t<decltype(set.debug)>>();

      return true;
    }
  };
} // namespace YAML
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

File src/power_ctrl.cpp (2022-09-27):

#include "power_ctrl.hpp"
#include "config.hpp"

void ShiftReg::init() const {
  pinMode(SHIFT_REG_OUTPUT_EN_PIN, OUTPUT);
  disableOutput();

  pinMode(SHIFT_REG_DATA_CLK_PIN, OUTPUT);
  digitalWrite(SHIFT_REG_DATA_CLK_PIN, LOW);

  pinMode(SHIFT_REG_OUTPUT_UPDATE_PIN, OUTPUT);
  digitalWrite(SHIFT_REG_OUTPUT_UPDATE_PIN, LOW);

  pinMode(SHIFT_REG_DATA_PIN, OUTPUT);
  digitalWrite(SHIFT_REG_DATA_PIN, LOW);
}
void ShiftReg::enableOutput() const { digitalWrite(SHIFT_REG_OUTPUT_EN_PIN, LOW); }
void ShiftReg::disableOutput() const { digitalWrite(SHIFT_REG_OUTPUT_EN_PIN, HIGH); }
void ShiftReg::update(uint16_t newValue) const {
  // check my assumptions
  static_assert(LOW == 0x00);
  static_assert(HIGH == 0x01);

  for (uint8_t i = 0; i < 16; ++i) {
    uint8_t targetVal = newValue & 1;
    // first write the serial data
    digitalWrite(SHIFT_REG_DATA_PIN, targetVal);
    // then issue a rising clock edge
    digitalWrite(SHIFT_REG_DATA_CLK_PIN, HIGH);
    digitalWrite(SHIFT_REG_DATA_CLK_PIN, LOW);

    newValue >>= 1;
  }

  // finally update the outputs, again with a rising edge!
  digitalWrite(SHIFT_REG_OUTPUT_UPDATE_PIN, HIGH);
  digitalWrite(SHIFT_REG_OUTPUT_UPDATE_PIN, LOW);
}

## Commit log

2022-07-09 start with KiCAD pcb design
    [dryNoMorePCB.kicad_pcb, dryNoMorePCB.kicad_sch]
2022-07-09 hardware: add shift register & ethernet adapter
    [dryNoMorePCB.kicad_sch]
2022-07-10 more pcb progress
    [dryNoMorePCB.kicad_pcb, dryNoMorePCB.kicad_sch]
2022-07-12 more routing nightmares incoming
    [dryNoMorePCB.kicad_pcb, dryNoMorePCB.kicad_sch]
2022-07-16 almost done with the pcb
    [dryNoMorePCB.kicad_pcb, dryNoMorePCB.kicad_sch]
2022-07-17 add circuit tree icon files
2022-07-17 eth W5500: only connect 5V, add circuit tree icon to the backside
    [dryNoMorePCB.kicad_pcb, dryNoMorePCB.kicad_sch]
2022-07-17 more water level sensor code
2022-07-19 fix missing filling +5V zone, USB pump silkscreen numbering
    [dryNoMorePCB.kicad_pcb]
2022-07-19 remove board measurments from the silkscreen
    [dryNoMorePCB.kicad_pcb]
2022-07-19 pcb: update pwr label
    [dryNoMorePCB.kicad_pcb]
2022-07-24 adc measurement: invert percentage mapping
    [main.cpp]
2022-07-24 add arduino framework patches to avoid division by zero, yet Serial output remains broken
2022-07-29 hardware: fix input voltage polarity (J10), pump version
    [dryNoMorePCB.kicad_pcb, dryNoMorePCB.kicad_sch]
2022-07-31 more power saving stuff, fix pin initialization
    [config.hpp, main.cpp]
2022-07-31 fix shiftreg power mappings
    [config.hpp]
2022-08-06 telegram bot will need threads
2022-08-06 we will need to change the SPI settings
2022-08-06 telegram_bot: add tcp socket for communication with DryNoMore MCU
2022-08-07 main: extract adc measurement code
2022-08-07 main: keep track of status, ensure that warnings/errors are only sent once per sensor
    [lan.cpp, main.cpp]
2022-08-07 main: introduce powerSavingSettings function
2022-08-09 implement lan power down & energy saving modes
2022-08-11 fix printMultiLineRow
2022-08-11 print hardware failure status too
2022-08-12 generateTable: allow controlling where whitespaces are printed
2022-08-13 fix min buttons
2022-08-13 only add as many edit pump buttons as active
2022-08-13 add remaining edit buttons
2022-08-15 make default water sensor mapping & skip plant settings configurable
    [config.hpp]
2022-08-23 telegram_bot: clip -100, -10, +10, +100 buttons at min/max values
2022-08-25 git lfs track font files
2022-08-25 git lfs track freecad & stl files
2022-08-25 Add case CAD & STL files
    [Base.stl, DryNoMoreCase.FCStd, Top.stl]
2022-09-03 error msg: fix idx, move hwFailure code
    [lan.cpp, main.cpp]
2022-09-03 telegram bot: refine button texts
2022-09-03 report raw sensor data too
2022-09-03 report the unclamped adc measurement value!
2022-09-05 fix compile for debug modes
    [main.cpp]
2022-09-08 fix pin initialization
2022-09-08 early pin initialization to fully discharge capacitors
2022-09-10 ensure LEDs are off during sleep
2022-09-11 fix result code for warnings
    [main.cpp]
2022-09-11 new hardware revision: add mosfet to switch off the ethernet module
    [dryNoMorePCB.kicad_pcb, dryNoMorePCB.kicad_sch]
2022-09-27 implement ETH module power switching
2022-09-28 implicitly add missing SPI.begin()
    [lan.cpp]
2022-10-01 telegram_bot: yaml config fix settings decoding
    [main.cpp]
2022-10-01 update case design for HW rev 0.3 (untested)
    [DryNoMoreCase.FCStd, Top.stl]
2022-10-04 send HW failure message last
    [main.cpp]
2022-10-05 change nmos from DGS to SGD pinout to match an 2N7000
    [dryNoMorePCB.kicad_pcb, dryNoMorePCB.kicad_sch]
2022-10-06 add missing Ethernet powerup
    [lan.cpp]
2022-10-06 switch to input pullup for SPI signals to ensure ETH mosfet turns off
2022-10-08 more debug printing
2022-10-26 keep track of time used for irrigation and adjust sleep time accordingly
2023-05-08 more debug prints & add debug with normal cpu speed option
2023-05-08 simplyfy statusChanged checks & add another debug print
2023-05-08 add debug prints of the send & received settings struct
2023-05-08 fix printing hex bytes
2023-05-08 updateSettings: handle client.read response properly, wait for data & more debug prints
2023-05-08 dry_no_more_server: add more debug prints
